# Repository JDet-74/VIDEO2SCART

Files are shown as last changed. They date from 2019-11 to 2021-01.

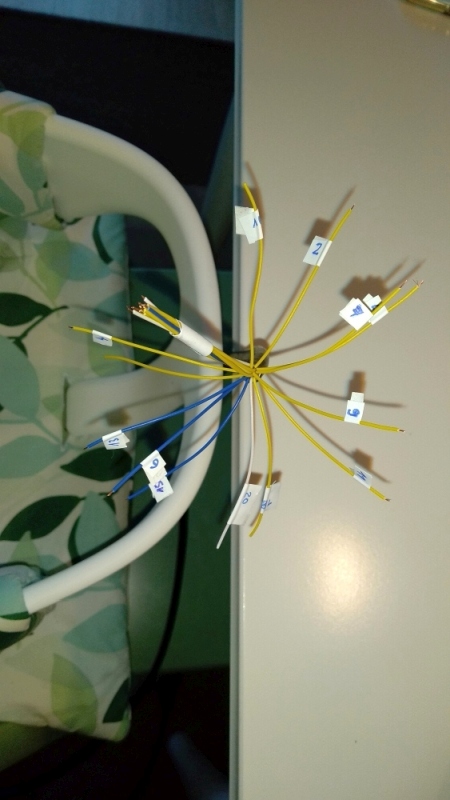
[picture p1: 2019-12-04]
cable_howto/cable_01.jpg

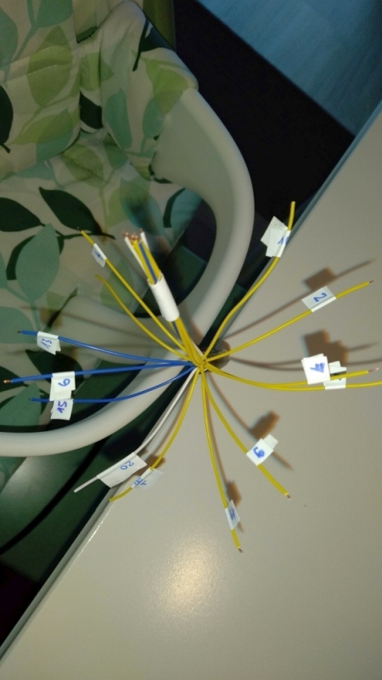
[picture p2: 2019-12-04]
cable_howto/cable_02.jpg

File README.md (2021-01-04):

# VIDEO2SCART
<p>this project is about a PCB that connects the Commodore C128 video outputs (RGBi & composite / S-Video) to a SCART display device!
I created this project online on www.easyEDA.com and ordered the PCBs from www.JLCPCB.com and the parts from www.LCSC.com</p> 

<h3>file / directories INFO:</h3>
<p><strong>3DPrint</strong> </br> the STL files and some pictures of the case ... ready for 3D printing</p>
<p><strong>PCB</strong></br> PCB_C128_VIDEO2SCART_JDet_assembling.pdf = PDF for assembling </br> PCB_C128_VIDEO2SCART_JDet_PCB.pdf = the PCB view </br> Gerber_C128_VIDEO2SCART_DET_1_20191116125402.zip = the GERBER Files for ordering the PCB from a PCB manufactorer.</p>
<p><strong>cable_howto</strong></br> read the @cable_info.txt for further information of building the cables. There are also links to reichelt.de ... a electronic store where you can order the cables. look at the pictures ... they are showing the whole building process.</p>
<p>Schematic_C128_VIDEO2SCART_JDet.pdf = the schematic that shows the circuit of all components.</p>
<p>partslist.csv = a list of all components and the part number to order them from LCSC.</p>
<p>Please read the cable assembling INFO PDFs ... coming soon.</p>
<p>special thanks to Peter Grigull for designing the case and sharing the STL files.</p>

<p><strong>switches:</strong></br> SW1 switches between the 80 col. and the 40 col. mode.</br> SW2 switches between video (composite) or s-video signal in the 40 col. mode</p>
<p><strong>jumper function:</strong></br> short left&middle pin - monochrome is syncing the 80 col. mode - that works GOOD.</br> short right&middle pin - NOR generated HSync&VSync signal (generated with the JFET) is syncing the 80 col. mode. I noticed that this function do not work! during testing on the bredboard it went all well ... that is a little bit odd ... but you do not need this, because the monochrome sync works GOOD. SORRY for that ...</p>

<p>cheers ... <strong>JDet</strong></p>
<h3>Contact</h3>
<p>For any questions (technical or experience), please use the issue tracking system of github.</p>

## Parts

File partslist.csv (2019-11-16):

ID | Name | Designator | Footprint | Quantity | Manufacturer Part | Manufacturer | Supplier | Supplier Part
1 | 5K | R12 | RES_ADJ-3.6X3.8 | 1 | VG039NCHXTB502 | Hokuriku Elec Industry | LCSC | C128557
2 | 470 | R1,R2,R3,R8,R9,R10 | 2010 | 6 | 2010W2J0471T4S | UniOhm | LCSC | C20427
3 | 1K | R4,R5,R6 | 2010 | 3 | 2010W2J0102T4S | UniOhm | LCSC | C20371
4 | 200 | R13,R14 | RES-ADJ_VG039 | 2 | VG039NCHXTB201 | HDK | LCSC | C128548
5 | 1M | R11 | 2010 | 1 | 2010W2J0105T4S | UniOhm | LCSC | C20377
6 | MTP125-1103S1 | U4 | SDIP-D-3_2.54 | 1 | MTP125-1103S1 | MINTRON | LCSC | C358685
7 | C128_VIDEO_DIN_8 | U2 | C128_VIDEO_DIN_8 | 1 |  |  | DET
8 | C128_RGBi_D_SUB_9 | U1 | C128_RGBI_D_SUB_9 | 1 |  |  | DET
9 | C128_SCART_OUT_1 | U3 | C128_SCART_OUT_1 | 1 |  |  | DET
10 | SSSU022800 | SW2 | SW-DIP-18.5X7 | 1 | SSSU022800 | ALPS Electric | LCSC | C160887
11 | BS170FTA | Q2 | SOT-23(SOT-23-3) | 1 | BS170FTA | DIODES | LCSC | C151050
12 | SSSU042100 | SW1 | SW-TH_12PIN_SSSU042100 | 1 | SSSU042100 | ALPS Electric | LCSC | C384610
13 | 100 | R7 | 2010 | 1 | 2010W2J0101T4E | UniOhm | LCSC | C54728

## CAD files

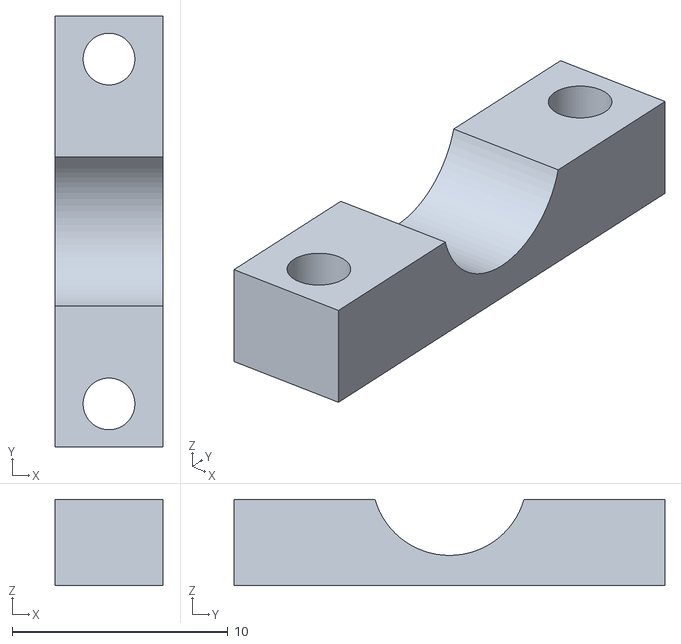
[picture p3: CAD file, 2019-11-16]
3DPrint/Leitungssicherung-einfach.stl
5.00 x 20.0 x 4.00

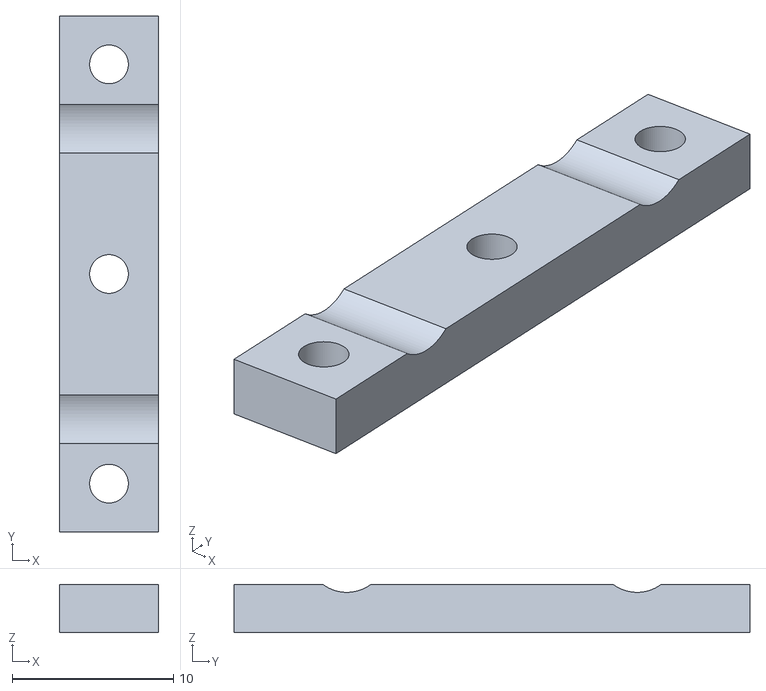
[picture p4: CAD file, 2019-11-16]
3DPrint/Leitungssicherung-doppelt.stl
6.16 x 32.0 x 3.00

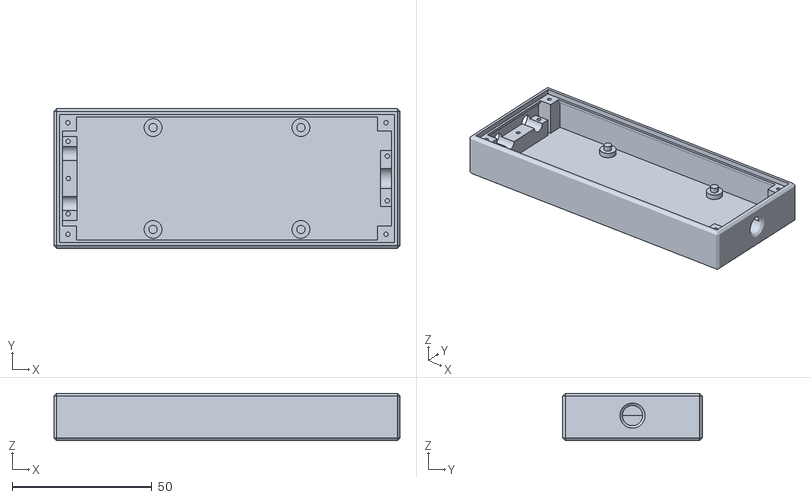
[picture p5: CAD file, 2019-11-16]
3DPrint/Gehaeuse.stl
124.0 x 50.0 x 17.0

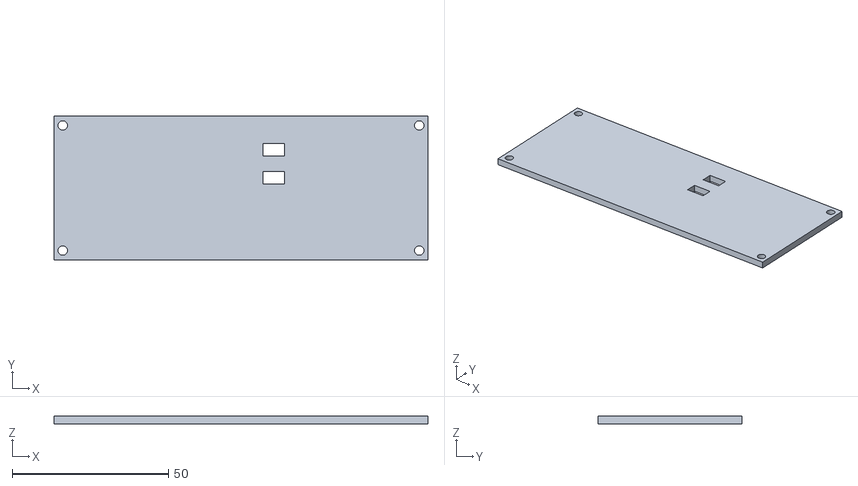
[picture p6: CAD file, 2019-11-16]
3DPrint/Deckel.stl
119.6 x 45.9 x 2.40

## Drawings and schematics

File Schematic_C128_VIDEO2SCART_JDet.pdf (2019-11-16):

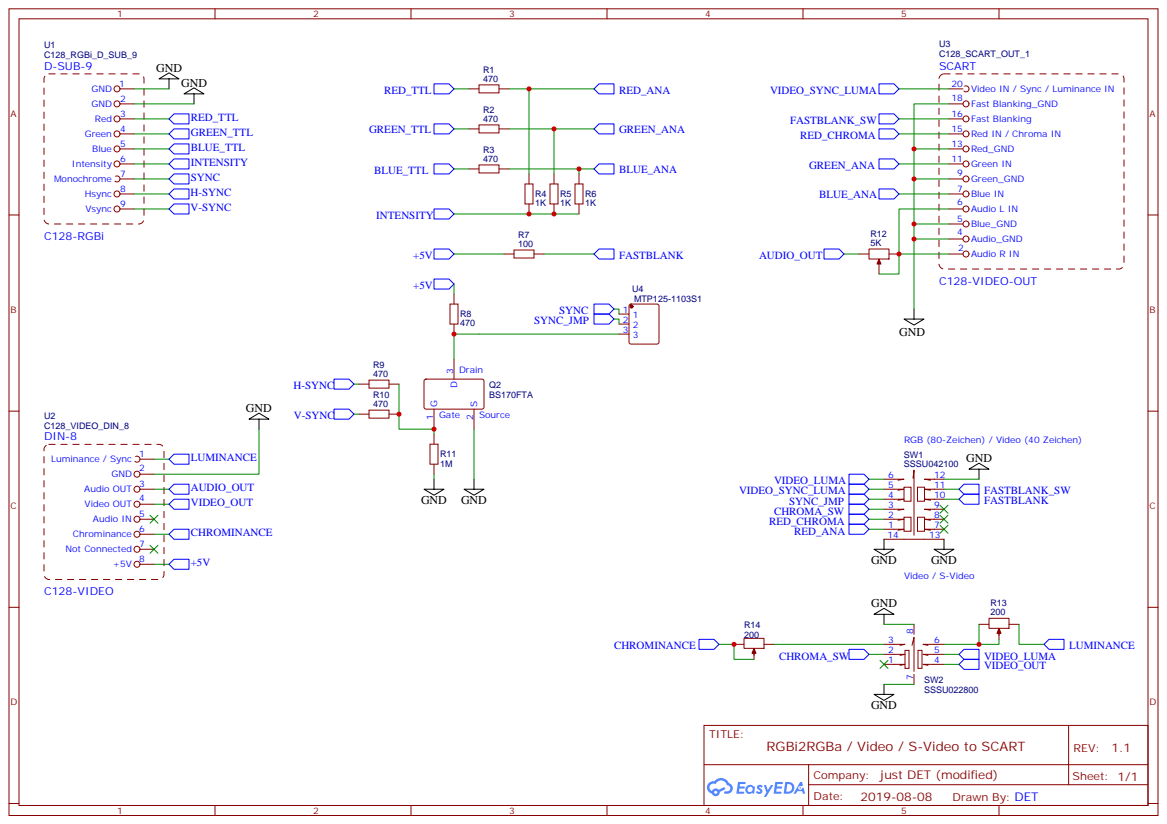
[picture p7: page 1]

Company: just DET (modified)

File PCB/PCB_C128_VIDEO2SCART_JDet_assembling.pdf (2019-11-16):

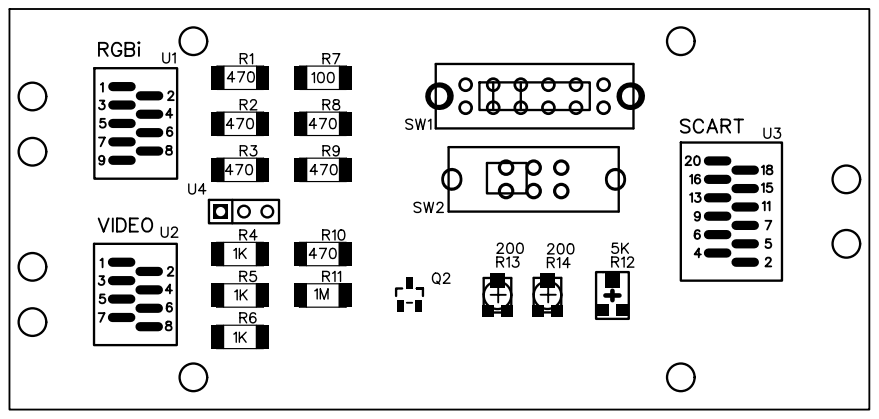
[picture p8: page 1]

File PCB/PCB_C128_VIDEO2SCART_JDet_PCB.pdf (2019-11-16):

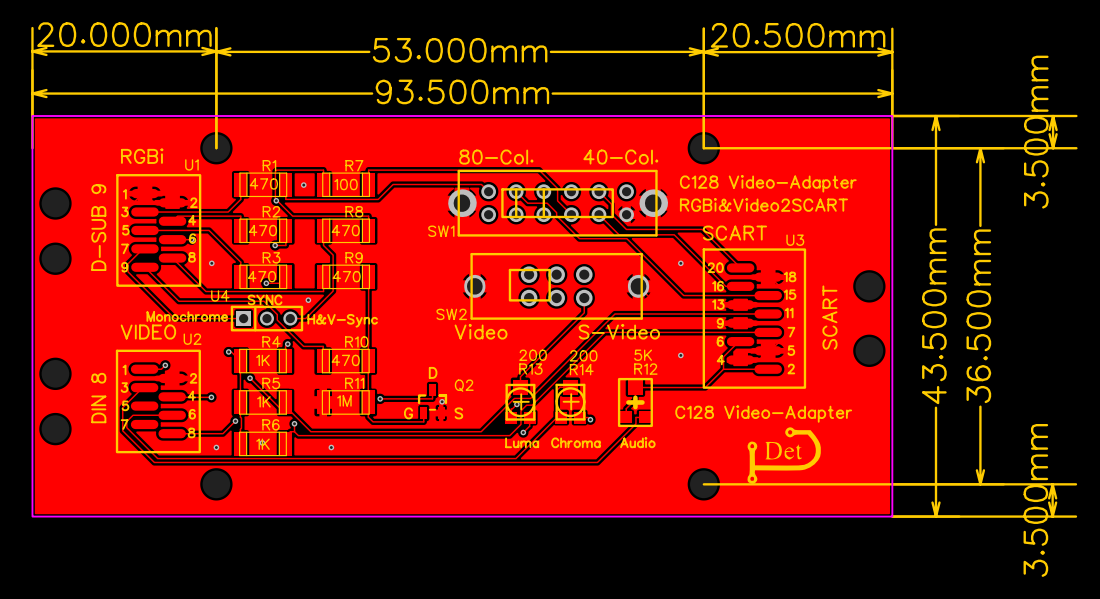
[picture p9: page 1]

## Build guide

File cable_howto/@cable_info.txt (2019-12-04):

my cable recommendations from http://www.reichelt.de

RGBI cable:
Art.Nr. AK 2187
D-SUB Kabel, 1:1, 9-pol., Stecker/Stecker, 3m
cut the cable into half and use one for the RGBI cable

Pin	color	info
++++++++++++++++++++
1	black	GND
	+screen
2	brown	GND
3	red	Red
4	orange	Green
5	yellow	Blue
6	green	Intensity
7	blue	Monochrome
8	purple	HSync
9	white	VSync

strip the cable isolation that the wires 1-9 are 5 cm long.
I connected the cable screen to GND (black) as shown.
the pictures shows the whole process.  

DIN-8 cable:
Art.Nr. MAS 80S 
DIN-Stecker, 8-polig, Hufeisenform
use the rest of the D-SUB cable to build the A/V cable 

Pin	color	info
++++++++++++++++++++
1	black	Luminance (luma)
2	brown	GND
	+white+screen
3	red	Audio OUT
4	orange	Video OUT
5	yellow	Audio IN
6	green	Chromiance (chroma)
7	blue	not connected
8	purple	+5 Volt

strip the cable isolation that the wires 1-9 are 3,5 cm long.
I connected the cable screen to GND (brown+white) as shown.
the pictures shows the whole process.  
a link to the pinout of the A/V socket:
https://www.c64-wiki.com/wiki/File:AudioVideo_8pol_Pinbelegung.gif

SCART cable:
Art.Nr. AK 315-15
Scart Kabel 21-pol Scart Stecker, 1,5 m
or 
Art.Nr. AK 315-30
Scart Kabel 21-pol Scart Stecker, 3 m

cut the lenght you wanna use and look at the pictures.
they show you where you can find the right wires. 
you just need 12 wires of the 21 wires.
a link to the pinout of a SCART Plug:
http://www.nairam.sk/scart.jpg

it is not easy to solder but possible :)

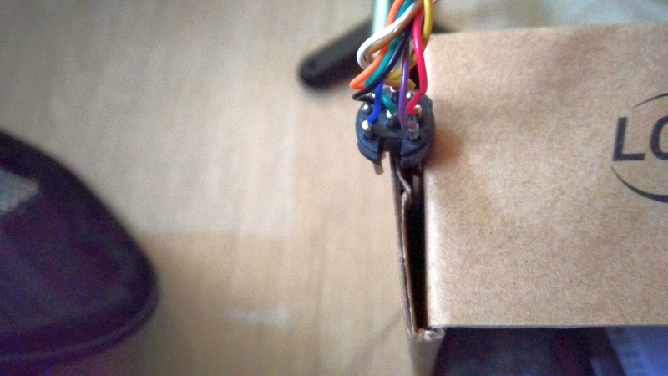
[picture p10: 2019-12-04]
cable_howto/cable_30.jpg

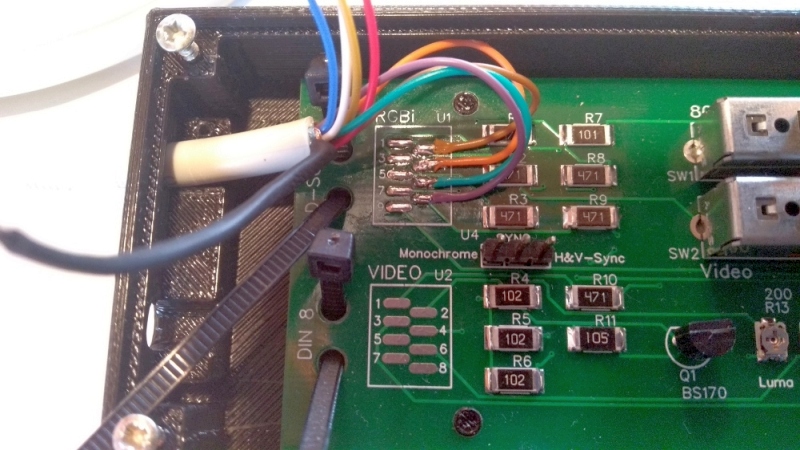
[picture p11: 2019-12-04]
cable_howto/cable_18.jpg

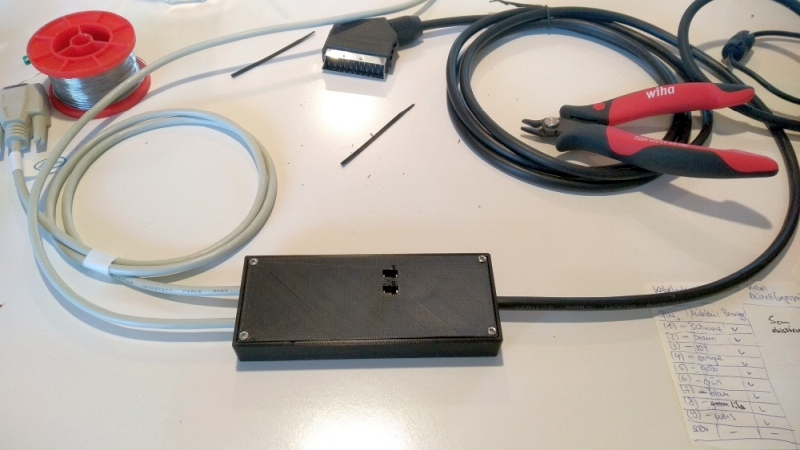
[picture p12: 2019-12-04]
cable_howto/cable_29.jpg

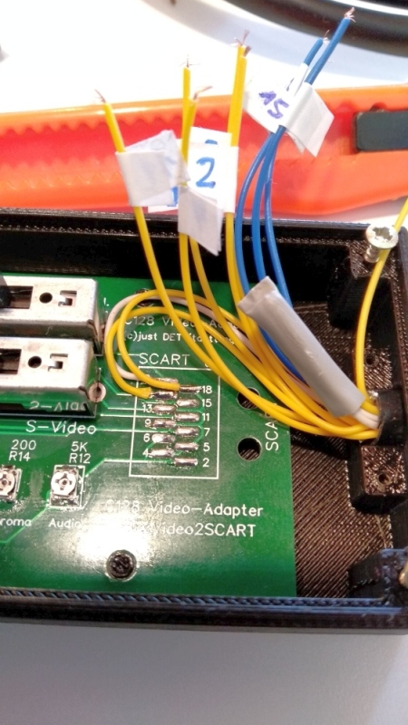
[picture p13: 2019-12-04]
cable_howto/cable_12.jpg

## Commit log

2019-12-04 Add files via upload
    read the @cable_info.txt for further informations.
2019-12-04 some pictures of my printed case.
